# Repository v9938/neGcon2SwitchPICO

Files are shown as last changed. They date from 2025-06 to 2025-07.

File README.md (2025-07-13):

# 俺はneGconをアケアカのリッジレーサでつかいたいんじゃ、<BR>ついでにAirCombat22も対応しておいた for RP2040<BR>(neGcon2SwitchPICO)
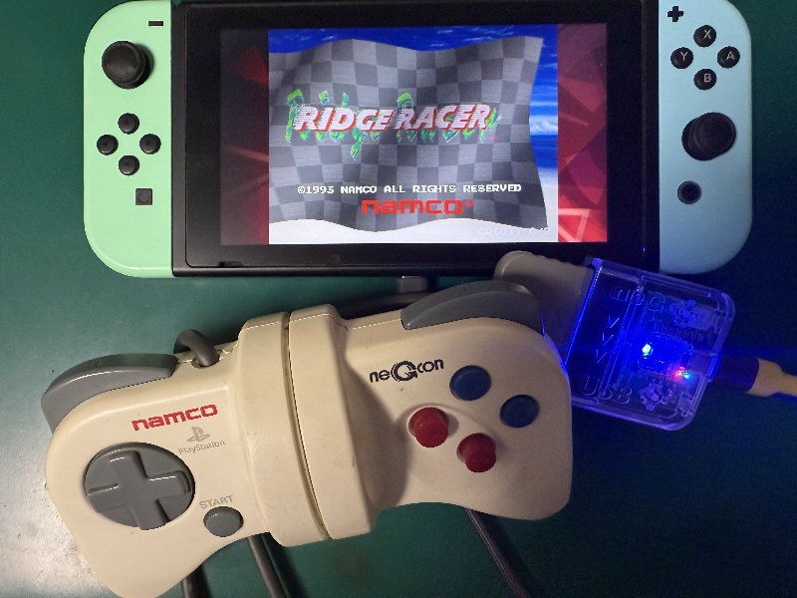
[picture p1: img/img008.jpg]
装置イメージ2
  

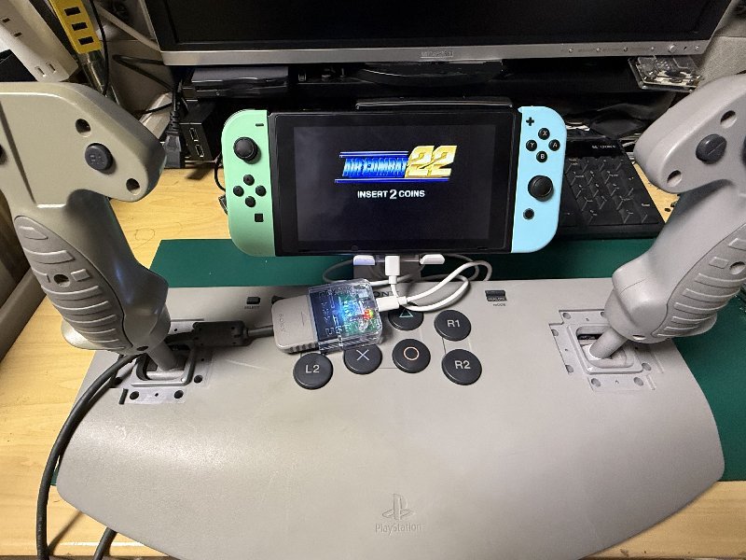
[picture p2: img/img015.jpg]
装置イメージ3
  

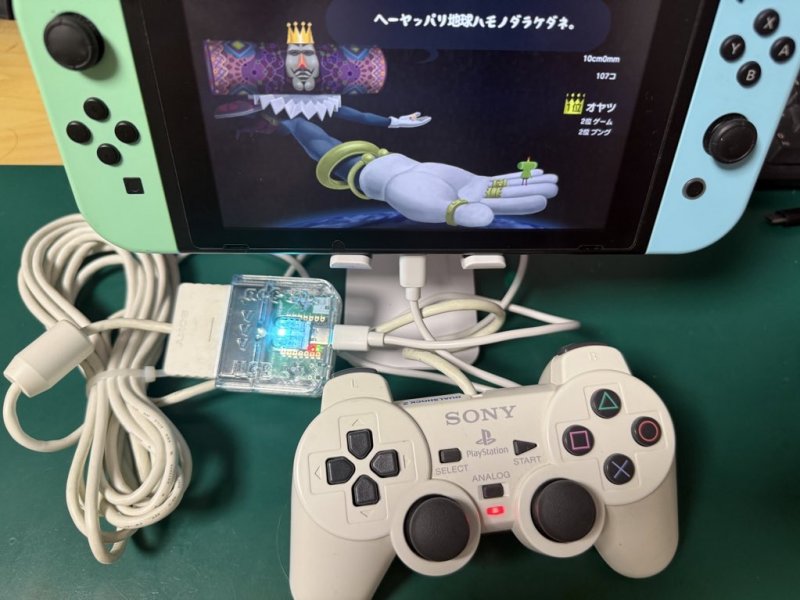
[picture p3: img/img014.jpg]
装置イメージ4
  

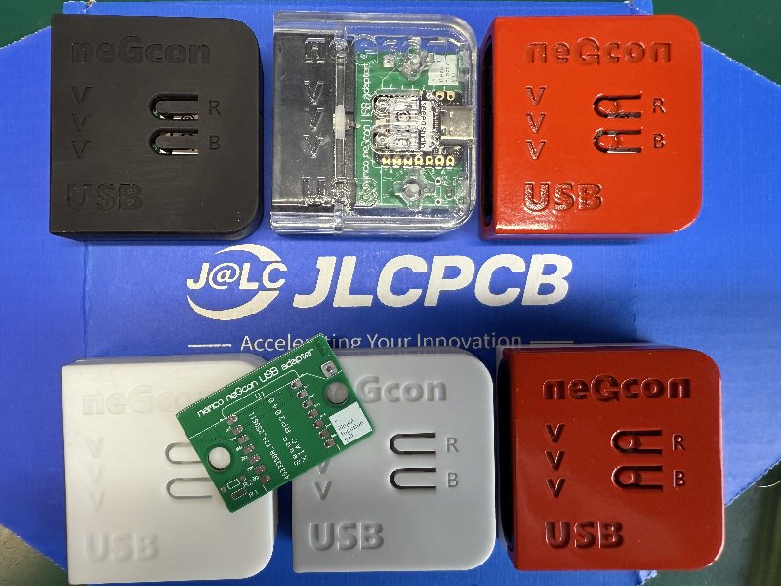
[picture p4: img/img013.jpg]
組み込みイメージ
  

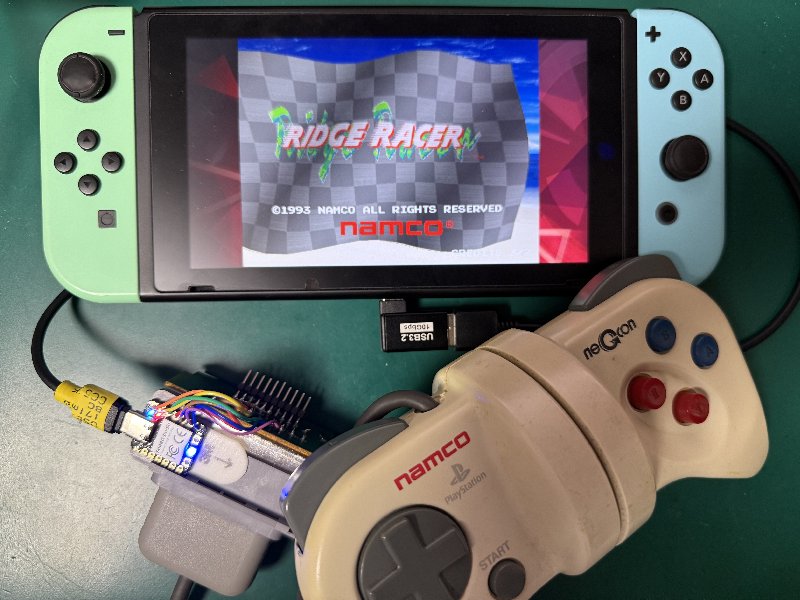
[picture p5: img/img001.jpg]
装置イメージ
  

良くあるプレステのコントローラをUSBゲームコントローラに変換するアダプタです。  
先日作ったNAMCO neGcon to Nintendo Switch ConverterはAVRで作っているため、  
色々と今だとイマイチなところが多いので改めてraspberry PICO系のマイコンボードで作り直しました。  

nintendo SWITCH向けに作りましたが、Windowsなどで汎用的に使用することが可能です。  

Nitendo Switch用アケアカ版リッジレーサでネジコンが使いたい！！

と勢いで雑に作った・・・のですが、頒布するために、もう少し真面目にコードを書き直して、  
バカでっかいFlightControllerをAirCombat22に対応させてみたり、  
DualShockの辺りをちゃんと、真面目に対応させて見たら悪くは無い出来の様な気がします。  

Switch2でも動きました・・・＼(^o^)／

## ■ 本製品の頒布について

下記ショップで取り扱っていただいています。  

###家電のKENちゃん  

完成品 (ケース色 赤/赤)  
<https://www.kadenken.com/view/item/000000001894>  

完成品 (ケース色 透明/赤)  
<https://www.kadenken.com/view/item/000000001895>  

キット版 (要半田付け　ケース無し）  
<https://www.kadenken.com/view/item/000000001893>  

※売り切れ時は、追加生産個数の参考にしたいので  
　「再入荷のお知らせを受け取る」おいていただけると幸いです。  

## 作り方
どこの誤家庭にもある、Seeed XIAO RP2040 または raspberry PICOボートとプレステのコントローラをつないでください。  
1KΩのプルアップ抵抗は必須です。DATAと3.3Vの間につけてください  

## PS1/PS2 joypad との配線 

|PSX Pin | PSX Signal | XIAO RP2040 | raspberry PICO | RP2040 Signal |
| :- |  :- |  :- |  :- |  :- |
| 1 | DAT | 9 | GP4 | MISO<BR>[need pullup by 1k owm registor to 3.3V] |
| 2 | CMD | 10 | GP3 | MOSI |
| 3 | 9V<BR> (for motor, If you not necessary NC)| (VCC) | (VSYS) | +5V |
| 4 | GND | GND | GND | Power GND |
| 5 | 3.3V | +3V3 | 3V3 | Power 3.3V |
| 6 | Attention | 7 | GP1 | GPIO1 (Controller Select) |
| 7 | CLK | 8 | GP2 | SCK |
| 8 | NC | - | - |
| 9 | ACK | - | - |

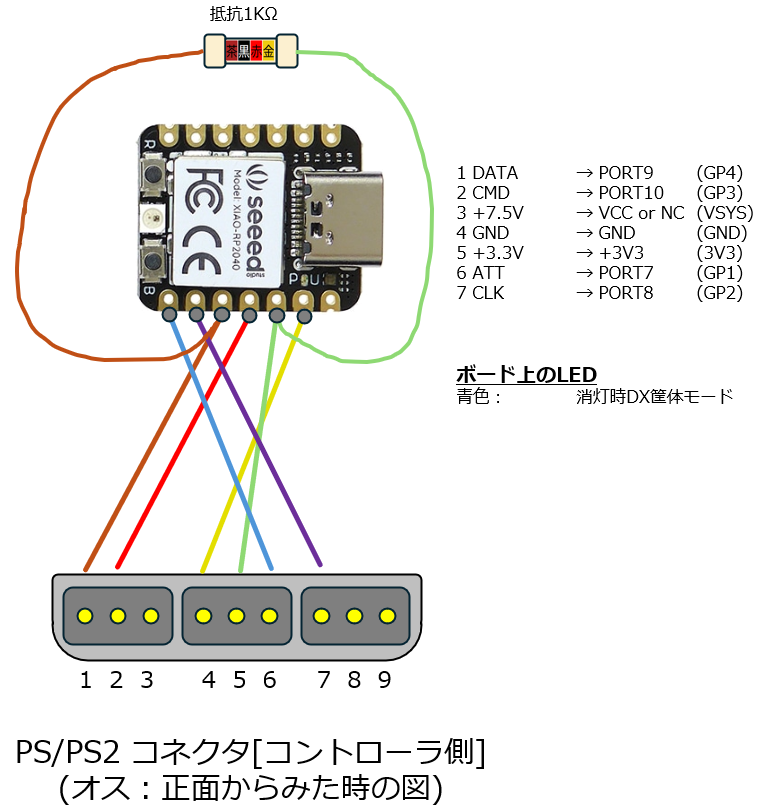
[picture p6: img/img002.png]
XIAO配線イメージ
  

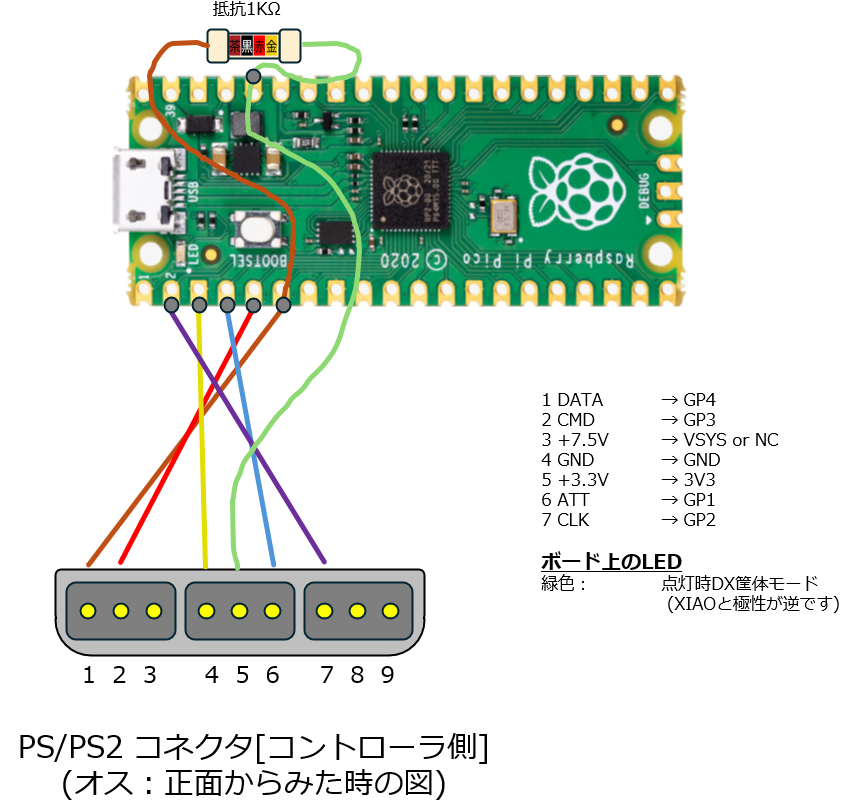
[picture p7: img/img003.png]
PICO装置イメージ
  

## Firmware書き込み方法
マイコンボード上にあるBボタンまたはBOOTSELボタンを押しながらUSBケーブルを接続してください。  
PCに接続した後も念のため数秒程度はボタンを離さないようにしてください。  
上手く接続できれば回路が「RPI-RP2」という名前で、USBメモリのように認識されます。  
「RPI-RP2」を開き、「xxxxx.uf2」ファイルをドラッグ&ドロップしたら完了です。  

「./firmware」のフォルダにコンパイル済のファイルが置いてあります。  

## ボタン配置について
接続するコントローラによってボタン配置や挙動が自動的に変更されます。  

## neGcon接続時のボタン配置
アケアカのリッジレーサに最適化されたモードです。  
neGcon接続時は[B]のBOOTボタンを押す事で設定を切り替えられます。(V1.20以降)  
また、neGcon/JoyCon/ANALOG JOYSTICK(SCPH-1110)接続時は、BOOTボタンをそのまま10秒程度更に長押しをすると、  
LEDが点滅し、最大角設定モードになります。(V1.30以降)  

アナログの感度に関しては、本Adapterでも補正を少しいれていますが、さらに調整が必要な場合は、  
アケアカ内のゲーム内の「設定」→「ボタン」→「こだわりのボタン設定」→「感度設定」で調整可能です。  

各モードのLED色は下記の通りです。  
| LEDの色 | モード |
| :- |  :- |
| 青色 | STD筐体モード  |
| 黄色 | DX筐体モード  |
| 紫色 | STD筐体モード(I/IIボタンSWAP)  |
| 緑色 | DX筐体モード(I/IIボタンSWAP)  |
| 白色 | デジタルモード  |
| 青点滅 | 最大角設定モード[ネジコン/ANALOG JOYSTICK(SCPH-1110)のみ]  |

### ボタン配置(アケアカ：リッジレーサ STD筐体モード)
|neGconボタン | Nintendo Switchコントローラ | 備考 |
| :- |  :- |  :- |
| ねじり (アナログ) | 左アナログスティックのX | 左アナログスティックのYは常にCenterです。 |
| I (アナログ) | 左アナログスティックのY 上方向 |  |
| II (アナログ) | 左アナログスティックのY 下方向 |  |
| L (アナログ) | Lボタン | 押し込まないと反応しません |
| R (デジタル) | Rボタン | |
| A (デジタル) | Aボタン | |
| B (デジタル) | Yボタン | |
| START (デジタル) | ＋ボタン |  |

### ボタン配置(アケアカ：リッジレーサ DX筐体モード)
| neGconボタン | Nintendo Switchコントローラ | 備考 |
| :- |  :- |  :- |
| ねじり (アナログ) | 左アナログスティックのX | 左アナログスティックのYは常にCenterです。 |
| I (アナログ) | ZRボタン | 押し込み量によって連射速度が変わります |
| II (アナログ) | ZLボタン | 押し込み量によって連射速度が変わります |
| L (アナログ) | Lボタン |  押し込まないと反応しません |
| R (デジタル) | Rボタン | |
| A (デジタル) | Aボタン | |
| B (デジタル) | Yボタン | |
| START (デジタル) | ＋ボタン |  |

## ANALOG JOYSTICK (SHPH-1110)接続時のボタン配置
アナログの感度に関しては、  
ゲーム内の「設定」→「ボタン」→「こだわりのボタン設定」→「感度設定」で調整可能です。  

### ボタン配置(アケアカ：AirCombat22モード)
| SHPH-1110 | Nintendo Switchコントローラ | 備考 |
| :- |  :- |  :- |
| 左スティック (アナログ) | 右アナログスティック | 操縦桿 |
| 右スティック (アナログ) | 左アナログスティック | スロットル |
| 右スティック HATスイッチ | 十字キー |  |
| SELECT | -ボタン |  |
| START  | +ボタン | メニュー |
| △ | Xボタン | クレジット |
| ○  | Aボタン | ミサイル |
| □ | Bボタン | バルカン |
| ✕  | Yボタン | START(視点切り替え)|
| L1  | ZLボタン |  |
| L2  | Lボタン |  |
| R1  | ZRボタン |  |
| R2  | Rボタン |  |

## DUALSHOCK/DUALSHOCK2接続時のボタン配置
### ボタン配置
| DUALSHOCK/DUALSHOCK2 | Nintendo Switchコントローラ | 備考 |
| :- |  :- |  :- |
| 左スティック (アナログ) | 左アナログスティック |  |
| 右スティック (アナログ) | 右アナログスティック |  |
| ○ (アナログ) | 未使用 | DUALSHOCK2のみ |
| □ (アナログ) | 未使用 | DUALSHOCK2のみ |
| 十字キー | 十字キー |  |
| SELECT | -ボタン |  |
| START  | +ボタン |  |
| △ | Xボタン | |
| ○  | Aボタン | |
| □ | Yボタン | |
| ✕  | Bボタン | |
| L1  | Lボタン |  |
| L2  | ZLボタン |  |
| R1  | Rボタン |  |
| R2  | ZRボタン |  |

## その他プレステコントローラ接続時のボタン配置
### ボタン配置
| プレステコントローラ | Nintendo Switchコントローラ | 備考 |
| :- |  :- |  :- |
| 十字キー | 十字キー |  |
| SELECT | -ボタン |  |
| START  | +ボタン |  |
| △ | Xボタン | |
| ○  | Aボタン | |
| □ | Yボタン | |
| ✕  | Bボタン | |
| L1  | Lボタン |  |
| L2  | ZLボタン |  |
| R1  | Rボタン |  |
| R2  | ZRボタン |  |

## 最大角度設定モードについて
neGcon/JoyCon/ANALOG JOYSTICK(SCPH-1110)接続時は、[B]のBOOTボタンを長押しをすると、  
LEDが点滅し、最大角設定モードになります。(V1.30以降)  

このモードで最大角を設定することでユーザ自身がneGcon/JoGconの捻り最大角度、  
ANALOG STICKでは操作時の最大角度を設定することができます。  

### 最大角の設定方法  
対応コントローラを接続し、[B]のBOOTボタンを10秒程度更に長押しすると当該モードに入ります。  

| LEDの色 | モード |
| :- |  :- |
| 青点滅 | 最大角設定モード[ネジコン/ANALOG JOYSTICK(SCPH-1110)のみ]  |

当該モードに入ったら、設定したい最大角度を実際に操作し、パッドの「スタートボタン」を一回押してください。  
LEDの点滅が止まり、元のモードに戻ります。設定値は自動で保存されます。  

初期値に戻したい場合は、コントローラやのニュートラル状態にして、パッドの「スタートボタン」を押してください。  
また、キャンセルは、[B]のBOOTボタンを1回押してください。  

## 専用基板および筐体について

下記フォルダーに、PCBデータと筐体データがおいてあるので JLCPCBさんの辺りに、  
まとめてぶん投げると一番安い仕様を選択すれば大体、基板は$5+送料、筐体は$8+送料で仕上がるはずです。  

<https://github.com/v9938/neGcon2SwitchPICO/tree/main/pcb>

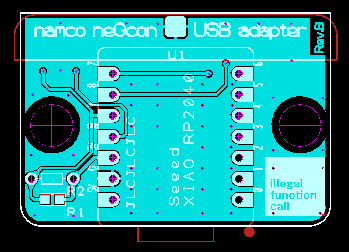
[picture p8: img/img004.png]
基板イメージ
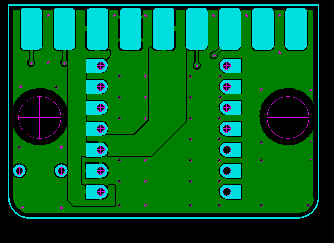
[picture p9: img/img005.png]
基板イメージ2
   
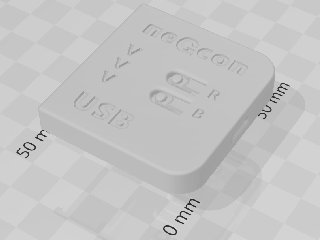
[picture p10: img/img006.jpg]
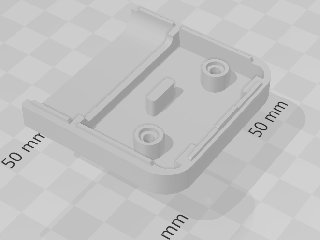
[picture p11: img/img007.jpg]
   

※専用基板および完成品の頒布は現在準備中です。  
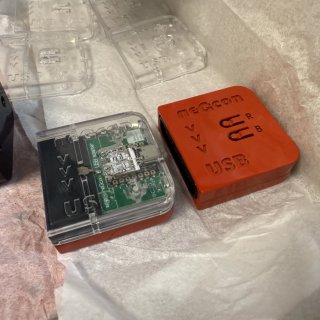
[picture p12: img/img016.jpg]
頒布筐体
  

## パーツリスト  
|部品番号 | 部品名 | 参考 購入先 |
| :- |  :- |  :- |
| U1 | Seeed XIAO RP2040 | 秋月電子 ￥980 |
| R1 | 未実装 | ※R1かR2のどちらかを実装 |
| R2 | 1KΩ1/6W | 秋月電子 1袋100本入 ￥120 |
| 番号なし | PSコントローラコネクタ | 秋月電子 Vstone VS-C1接続用基板側コネクター ￥300 |
| その他 | 2.6mmx12mm タッピングねじ(サラ) | 筐体で使う固定のネジになります。 |

## 組み立て方法  
それほどパーツ数が多くないので、下記写真の様に組み立てください。  
PSコネクタは実装後に、曲げると壊れるので表側のタブも少し曲げて、基板にハンダした方が良いです。  

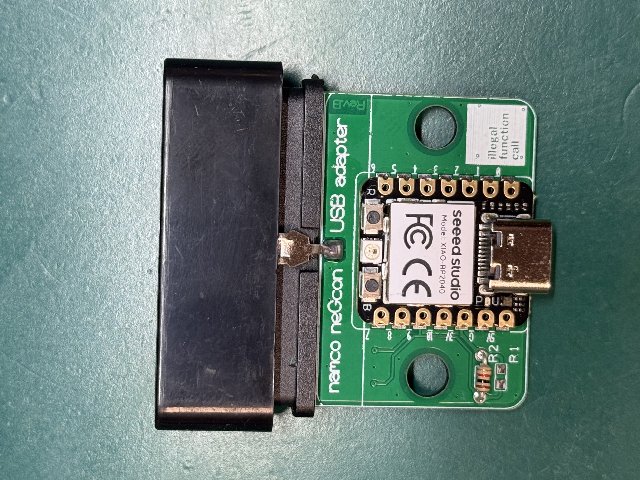
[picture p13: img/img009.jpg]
基板表
  
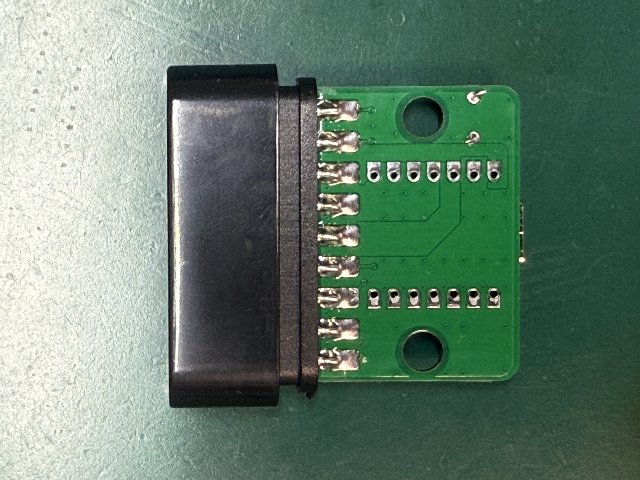
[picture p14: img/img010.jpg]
基板裏
  

筐体に入れる場合はマイコンボードに付属のヘッダピンは使わない様にして実装してください  
また、PSコネクタを半田付けする時に筐体に一度組み込んでハンダしましょう。  
(1mm程度基板から浮いて実装します)  

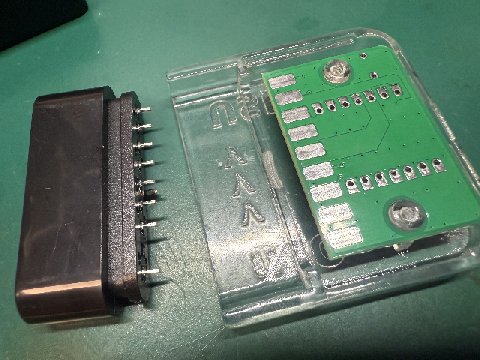
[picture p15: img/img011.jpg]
組み込み1
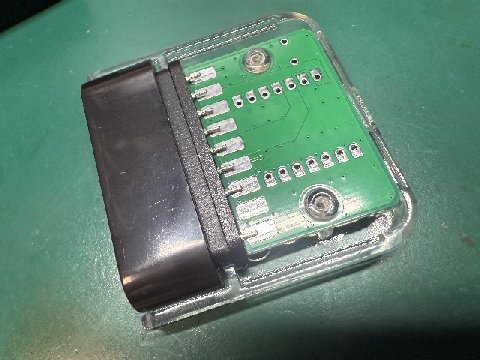
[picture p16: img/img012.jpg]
組み込み2
  

## コントローラの遅延について  
本変換機の遅延は、USB Data Frameで1パケット分になります。  
変換機でのUSB Data Frameの要求値は1msですが、USB Data Frameの送信間隔はHOSTが決めています。  
そのため、実際のキー入力から遅延時間はHOSTにより変わります。  
こちらで計測した範囲では以下の様になっていました。  

|USB HOST | USB Data Frame間隔 | 遅延時間 |
| :- |  :- |  :- |
| Switch/Switch2 | 約7.5ms | 15ms～22.5ms |
| Windows系 | 約1.5ms | 3ms～4.5ms |

### PS1 CONTROLLER(SCPH-1080)のLボタンを押した時の実測値  
※Lボタンを押した時が0ms →「USB DATA 10 00 08 80 80 80 80 00」 がLボタンを押した時のデータ  

■nintendo SWITCH2
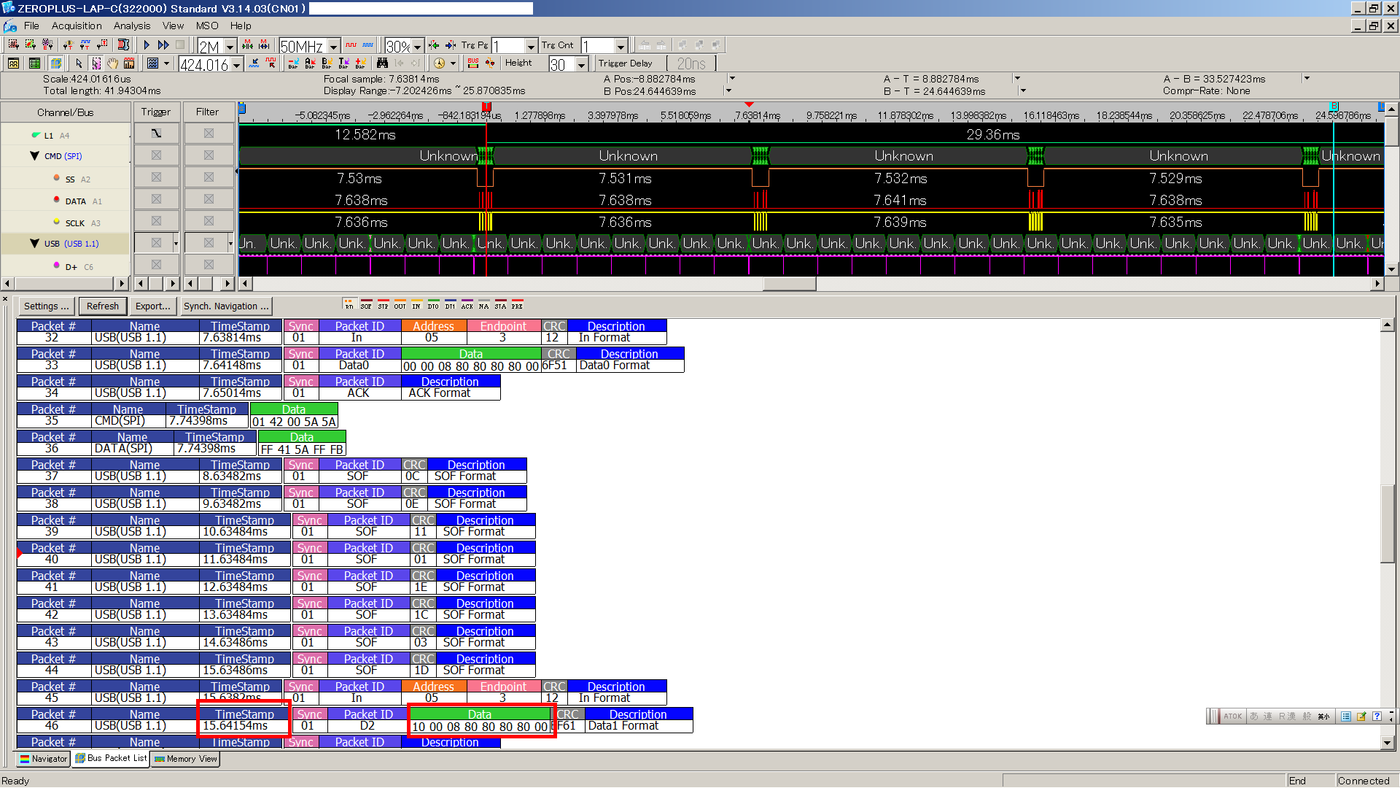
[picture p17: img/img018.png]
遅延Switch2
 
■Microsoft Windows11
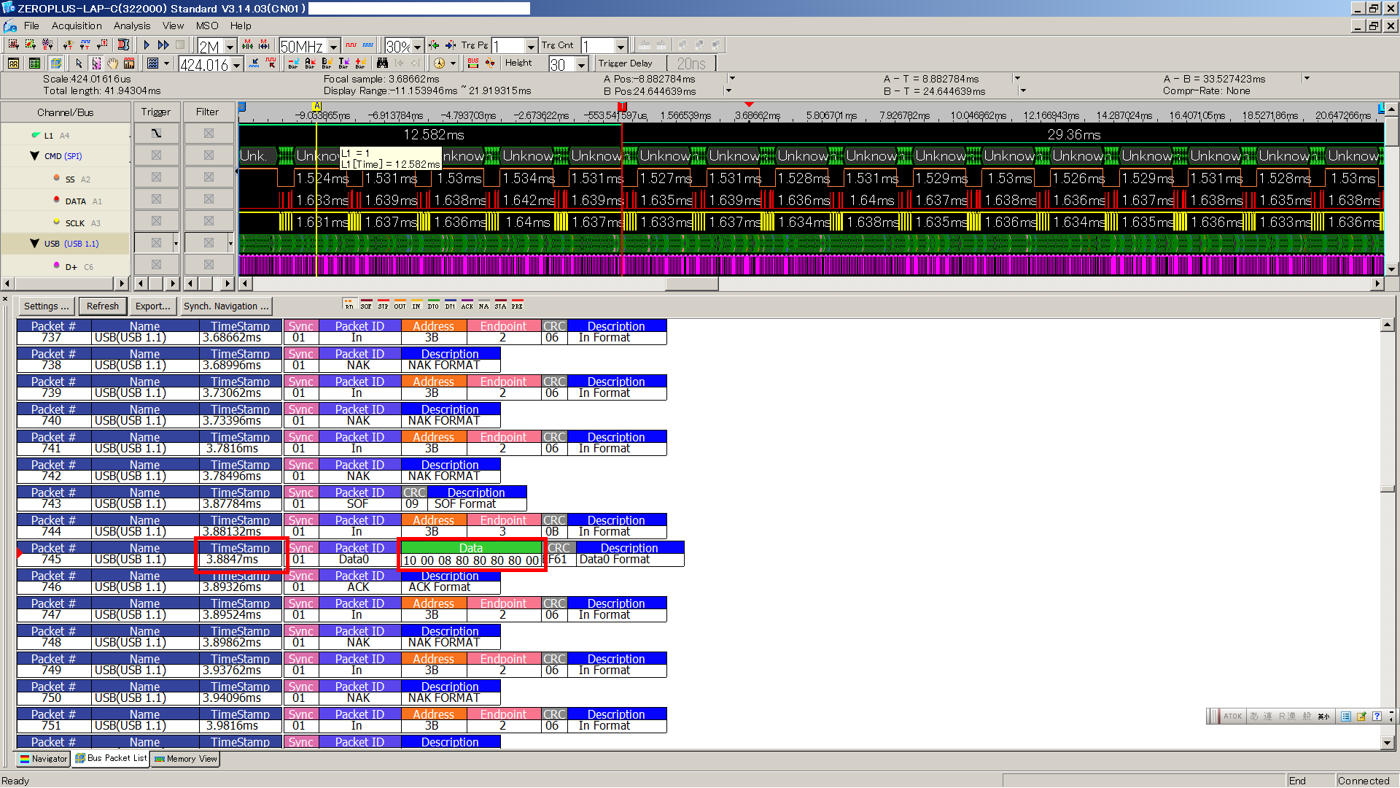
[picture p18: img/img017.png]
遅延Windows
 

## 使用したlibraryについて  
本ソフトは下記libraryを利用しています。  

### Adafruit_NeoPixel
<https://github.com/adafruit/Adafruit_NeoPixel>  

### Adafruit_TinyUSB_Library
<https://github.com/adafruit/Adafruit_TinyUSB_Arduino>

### PsxNewLib  
<https://github.com/SukkoPera/PsxNewLib>  

### SwitchControllerPico  
<https://github.com/sorasen2020/SwitchControllerPico>  

## おまけ  
JLCPCBさんがやっているOpen-Source Engineer Storiesに参加中です。  
下記ポストをリポストしてもらえると嬉しいです。  

<https://x.com/v9938/status/1938441988971405770>

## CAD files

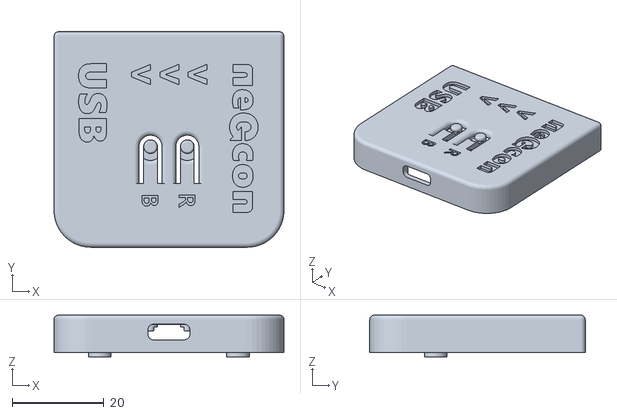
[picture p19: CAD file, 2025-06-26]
pcb/case/NEG2USB_CASE_TOP.stl
50.0 x 46.9 x 9.10

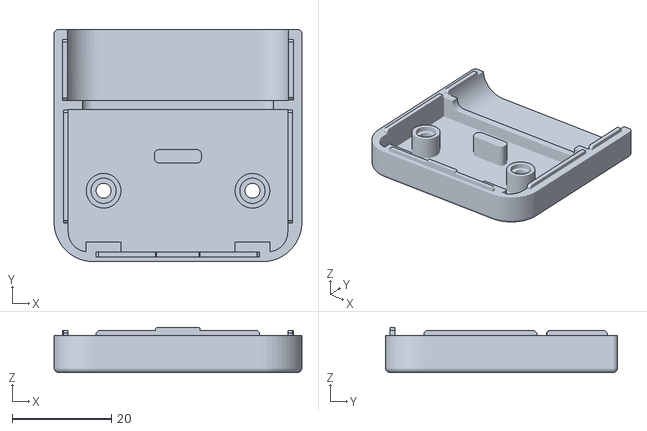
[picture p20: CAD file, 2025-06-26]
pcb/case/NEG2USB_CASE_BOTTOM.stl
50.0 x 46.9 x 9.10

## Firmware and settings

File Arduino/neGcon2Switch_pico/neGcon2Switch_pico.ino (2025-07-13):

////////////////////////////////////////////////////////////////////////
//
// PSX NeG Controller to Switch Joystick Sample
// raspberry PICO version
// Copyright 2025 @V9938
//
//	25/06/07 V0.1	1st version
//	25/06/07 V0.2	fix I/II/L Analog Value
//  25/06/10 V0.5   1st PICO version
//  25/06/11 V0.6   Support NeoPixel
//  25/06/11 V0.7   Support DX mode
//  25/07/03 V1.0   Support Aircombat22 mode with SCPH1110
//                  Fixed bug Digtal mode setting
//  25/07/03 V1.1   Support Controller HORI ANALOG SHINDOU PAD
//  25/07/12 V1.2   Support I/II button swap mode
//                  Fixed bug neGcon mode setting
//                  Support save & restore neGcon mode
//                  Change LED Pattern standard PSX Controller
//                  Adjust I/II button value (x1.1)
//  25/07/13 V1.3   Support maximum tilt setting(neGcon/Analog Stick).
//
//
// This program requires same librarys
// "Adafruit_NeoPixel"
//
// "PsxNewLib”
// https://github.com/SukkoPera/PsxNewLib
//
// "SwitchControllerPico"
// https://github.com/sorasen2020/SwitchControllerPico
//
// USB Stack setting "Adafruit_TinyUSB_Library"
// If modifying the PID/VID values in 'board.txt' is not possible at v2.xx IDE,
// please add the settings to the file listed below."
//
// C:\Users\[UserName]\Documents\Arduino\libraries\Adafruit_TinyUSB_Library\src\arduino\Adafruit_USBD_Device.cpp
// // added custom PID
// #define USB_PRODUCT     "Pokken Tournament DX Pro Pad"
// #define USB_MANUFACTURER "HORI"
// #define USB_VID 0x0f0d
// #define USB_PID 0x0092
//
////////////////////////////////////////////////////////////////////////

#include "Arduino.h"
#include "PsxControllerPICO_HwSpi2.h"
#include "SwitchControllerPico.h"
#include "NintendoSwitchControllPico.h"
#include <Adafruit_NeoPixel.h>
#include <EEPROM.h>

//#define SERIALVAL_OUT

// EEPROMの設定
#define EEPROMSIZE 256
// EEPROMのアドレス配置
#define EEPADR_NEGMODE 3
#define EEPADR_NEG_NEGMAX 4
#define EEPADR_ANALOG_STICKMAX 5

// neGcon ハンドルアナログ値の補正
// これ以上の補正が必要な場合は、設定→ボタン→こだわりのボタン設定→感度設定を弄ってください。
#define NEG_CALIB 1.2

// neGcon ボタン アナログ値の補正
// これ以上の補正が必要な場合は、設定→ボタン→こだわりのボタン設定→感度設定を弄ってください。
#define NEG_CALIB_B 1.1

//NeoPixelの設定
#define NUMPIXELS 1
#define NEO_PWR 11  //GPIO11
#define NEOPIX 12   //GPIO12

//Stick Mode
#define MODE_STD 0
#define MODE_DX 1
#define MODE_AIRCON22 2
#define MODE_ANALOG 3
#define MODE_STDSWAP 4
#define MODE_DXSWAP 5
#define MODE_NEGDIGTAL 6
#define MODE_DIGTAL 7

#define MODE_SETTING_NEG 98
#define MODE_LOST 99

//PWM modeの1LOOP回数 数字を細かくするとON-OFF間隔が短くなる(8ms x PWM_LOOP)
#define PWM_LOOP 30


/** \brief Pin used for Controller Attention (ATTN)
 *
 * This pin makes the controller pay attention to what we're saying. The shield
 * has pin 10 wired for this purpose.
 */
const unsigned int PIN_PS2_CMD = 4;  //MOSI
const unsigned int PIN_PS2_DAT = 3;  //MOSO
const unsigned int PIN_PS2_CLK = 2;  //SCK
const unsigned int PIN_PS2_ATT = 1;  //CS

// Set up the speed, data order and data mode
static SPISettings spiSettings(250000, LSBFIRST, SPI_MODE3);

/** \brief Pin for Button Press Led
 *
 * This led will light up whenever a button is pressed on the controller.
 */
const unsigned int PIN_CONNECT = 25;   // BLUE
const unsigned int PIN_ERRORLED = 17;  // RED
const unsigned int PIN_GOODLED = 16;   // GREEN

bool haveController = false;
/** \brief Dead zone for analog sticks
 *  
 * If the analog stick moves less than this value from the center position, it
 * is considered still.
 * 
 * \sa ANALOG_IDLE_VALUE
 */
const byte ANALOG_DEAD_ZONE = 50U;

PsxControllerPICO_HwSpi<PIN_PS2_ATT> psx;

const uint8_t desc_hid_report[] = {
  CUSTOM_DESCRIPTOR
};

Adafruit_USBD_HID usb_hid(desc_hid_report, sizeof(desc_hid_report), HID_ITF_PROTOCOL_NONE, 2, false);
Adafruit_NeoPixel pixels(NUMPIXELS, NEOPIX, NEO_GRB + NEO_KHZ800);

// Controller Type
const char ctrlTypeUnknown[] PROGMEM = "Unknown";
const char ctrlTypeDualShock[] PROGMEM = "Dual Shock";
const char ctrlTypeDsWireless[] PROGMEM = "Dual Shock Wireless";
const char ctrlTypeGuitHero[] PROGMEM = "3rd Party Controller";
const char ctrlTypeOutOfBounds[] PROGMEM = "(Out of bounds)";

const char* const controllerTypeStrings[PSCTRL_MAX + 1] PROGMEM = {
  ctrlTypeUnknown,
  ctrlTypeDualShock,
  ctrlTypeDsWireless,
  ctrlTypeGuitHero,
  ctrlTypeOutOfBounds
};


// Controller Protocol
const char ctrlProtoUnknown[] PROGMEM = "Unknown";
const char ctrlProtoDigital[] PROGMEM = "Digital";
const char ctrlProtoDualShock[] PROGMEM = "Dual Shock";
const char ctrlProtoDualShock2[] PROGMEM = "Dual Shock 2";
const char ctrlProtoFlightstick[] PROGMEM = "Flightstick（SCPH-1110)";
const char ctrlProtoNegcon[] PROGMEM = "namco neGcon";
const char ctrlProtoJogcon[] PROGMEM = "namco Jogcon";
const char ctrlProtoOutOfBounds[] PROGMEM = "(Out of bounds)";

const char* const controllerProtoStrings[PSPROTO_MAX + 1] PROGMEM = {
  ctrlProtoUnknown,
  ctrlProtoDigital,
  ctrlProtoDualShock,
  ctrlProtoDualShock2,
  ctrlProtoFlightstick,
  ctrlProtoNegcon,
  ctrlProtoJogcon,
  ctrlTypeOutOfBounds
};

const Hat hatValue[0x10] = {
  Hat::CENTER,
  Hat::UP,
  Hat::RIGHT,
  Hat::UP_RIGHT,
  Hat::DOWN,
  Hat::CENTER,
  Hat::RIGHT_DOWN,
  Hat::CENTER,
  Hat::LEFT,
  Hat::LEFT_UP,
  Hat::CENTER,
  Hat::CENTER,
  Hat::DOWN_LEFT,
  Hat::CENTER,
  Hat::CENTER,
  Hat::CENTER
};

USB_JoystickReport_Input_t t_joystickInputData;
byte ledLx, ledLy, ledRx, ledRy, ledB1, ledB2, ledBL;
byte stickMode;
byte lxMax;
byte analogLxMax;


// EEPROMのClear関数
void eepromFormat() {
  Serial.println(F("EEP Write!"));
  for (int i = 0; i < EEPROMSIZE; i++) {
    EEPROM.write(i, 0);
  }
  EEPROM.write(0, 'c');
  EEPROM.write(1, 'n');
  EEPROM.write(2, 'f');
  EEPROM.write(EEPADR_NEGMODE, MODE_STD);
  EEPROM.write(EEPADR_NEG_NEGMAX, 255 / ((NEG_CALIB - 1) / 2 + 1));
  EEPROM.write(EEPADR_ANALOG_STICKMAX, 255);
  EEPROM.commit();
}

// EEPROM領域の確認
bool eepromCheck() {
  if (EEPROM.read(0) != 'c') return false;
  if (EEPROM.read(1) != 'n') return false;
  if (EEPROM.read(2) != 'f') return false;
  return true;
}

// neGconモードひねり値の最大値の復帰
byte restoreNegDegMax() {
  byte tmp;
  tmp = EEPROM.read(EEPADR_NEG_NEGMAX);

  // 有効値Check
  if (tmp < 0x80) {
    tmp = 255 / ((NEG_CALIB - 1) / 2 + 1);
    Serial.println(F("EEP Write!"));
    EEPROM.write(EEPADR_NEG_NEGMAX, tmp);
    EEPROM.commit();
  }

  return tmp;
}

// アナログスティックモードひねり値の最大値の復帰
byte restoreAnaDegMax() {
  byte tmp;
  tmp = EEPROM.read(EEPADR_ANALOG_STICKMAX);

  // 有効値Check
  if (tmp < 0x80) {
    tmp = 255;

    Serial.println(F("EEP Write!"));
    EEPROM.write(EEPADR_ANALOG_STICKMAX, tmp);
    EEPROM.commit();
  }

  return tmp;
}

// neGconモード設定の復帰
byte restoreNegStickMode() {
  byte tmp;
  tmp = EEPROM.read(EEPADR_NEGMODE);

  // 有効値Check
  switch (tmp) {
    case MODE_STD:
    case MODE_STDSWAP:
    case MODE_DX:
    case MODE_DXSWAP:
      break;

    default:
      tmp = MODE_STD;
      Serial.println(F("EEP Write!"));
      EEPROM.write(EEPADR_NEGMODE, tmp);
      EEPROM.commit();
      break;
  }

  return tmp;
}

// 絶対値 計算関数
int absoluteXY(byte lx) {
  int lx_tmp;

  if (lx < 0x80) lx_tmp = (int)(0xFF - lx);
  else lx_tmp = (int)lx;
  return lx_tmp;
}

// 補正値計算
int adjustXY(byte lx, byte max) {
  int lx_tmp;

  if (lx > 0x80) {
    lx_tmp = (int)((lx - 0x80)) * 0x7f / (max - 0x80);
    if (lx_tmp > 0x7f) lx_tmp = 0x7f;
    lx_tmp = 0x80 + lx_tmp;
  } else {
    lx_tmp = (int)((0x80 - lx)) * 0x7f / (max - 0x80);
    if (lx_tmp > 0x80) lx_tmp = 0x80;
    lx_tmp = 0x80 - lx_tmp;
  }
  return lx_tmp;
}


// CPU1では、NeoPixel LEDの点灯処理をさせる
void setup1() {  //core 0
  pixels.begin();
  pinMode(NEO_PWR, OUTPUT);
  digitalWrite(NEO_PWR, HIGH);
  delay(1000);
}
void loop1() {  //core 0
  static byte heartbeat_num = 0;
  static bool heartbeat_flag = true;

  switch (stickMode) {
      // neGconモード時の点灯パターン
    case MODE_STD:
      pixels.setPixelColor(0, pixels.Color(ledB1 / 2 + ledBL / 2, ledB2 / 2 + ledBL / 2, ledLx));
      pixels.show();
      break;

      // neGconモード時の点灯パターン（I/II SWAPモード)
    case MODE_STDSWAP:
      pixels.setPixelColor(0, pixels.Color(0x80 - ledB1 + ledB2, 0, ledLx));
      pixels.show();
      break;

      // neGconモード時の点灯パターン DXモード時のパターン
    case MODE_DX:
      pixels.setPixelColor(0, pixels.Color(ledB2 / 2 + ledBL / 2, ledLx, ledB1 / 2 + ledBL / 2));
      pixels.show();
      break;

      // neGconモード時の点灯パターン DXモード時のパターン（I/II SWAPモード)
    case MODE_DXSWAP:
      pixels.setPixelColor(0, pixels.Color(0, 0x80 - ledB1 + ledB2, ledLx / 2 + ledBL / 2));
      pixels.show();
      break;

    // neGconモード時の点灯パターン デジタルモード時
    case MODE_NEGDIGTAL:
      pixels.setPixelColor(0, pixels.Color(0x20, 0x20, 0x20));
      pixels.show();
      break;

      // フライトコントローラ接続時の点灯パターン
    case MODE_AIRCON22:
      pixels.setPixelColor(0, pixels.Color(ledRy / 4, ledLx / 8, ledRy / 8 + 0x40));
      pixels.show();
      break;

      // DualShock接続時の点灯パターン
    case MODE_ANALOG:
      pixels.setPixelColor(0, pixels.Color(0, ledRy / 4 + ledLx / 2, ledRy / 2 + ledRx / 4));
      pixels.show();
      break;

      // その他接続時の点灯パターン
    case MODE_DIGTAL:
      pixels.setPixelColor(0, pixels.Color(0x0, 0x4, 0x8));
      pixels.show();
      break;

    case MODE_SETTING_NEG:
      pixels.setPixelColor(0, pixels.Color(0x0, 0x0, heartbeat_num));
      pixels.show();
      break;


      // 残念賞
    default:
      pixels.clear();
      pixels.show();
      break;
  }

  //LEDの点滅処理数値計算
  if (heartbeat_num == 0) heartbeat_flag = true;
  else if (heartbeat_num == 255) heartbeat_flag = false;

  if (heartbeat_flag) heartbeat_num++;
  else heartbeat_num--;
}

void setup() {
  switchcontrollerpico_init();
  // wait until device mounted
  while (!TinyUSBDevice.mounted()) delay(1);
  switchcontrollerpico_reset();
  pinMode(PIN_CONNECT, OUTPUT);
  pinMode(PIN_ERRORLED, OUTPUT);
  pinMode(PIN_GOODLED, OUTPUT);

  digitalWrite(PIN_CONNECT, HIGH);
  digitalWrite(PIN_ERRORLED, HIGH);
  digitalWrite(PIN_GOODLED, HIGH);


  gpio_init(PIN_PS2_CLK);  //SCK
  gpio_set_dir(PIN_PS2_CLK, GPIO_OUT);
  gpio_put(PIN_PS2_CLK, HIGH);

  gpio_init(PIN_PS2_CMD);  //MOSI
  gpio_set_dir(PIN_PS2_CMD, GPIO_OUT);
  gpio_put(PIN_PS2_CMD, HIGH);

  gpio_init(PIN_PS2_DAT);  //MISO
  gpio_set_dir(PIN_PS2_DAT, GPIO_IN);
  gpio_pull_up(PIN_PS2_DAT);

  gpio_init(PIN_PS2_ATT);  //SS(GPIO)
  gpio_set_dir(PIN_PS2_ATT, GPIO_OUT);
  gpio_put(PIN_PS2_ATT, HIGH);

  SPI.beginTransaction(spiSettings);
  EEPROM.begin(EEPROMSIZE);
  if (eepromCheck() != true) eepromFormat();

  //	SPI.setSCK(PIN_PS2_CLK);
  //	SPI.setMOSI(PIN_PS2_CMD);
  //	SPI.setMISO(PIN_PS2_DAT);

  lxMax = restoreNegDegMax();
  analogLxMax = restoreAnaDegMax();
  stickMode = MODE_LOST;
  delay(300);

  //	Serial.begin (115200);
  //	while (!Serial) {
  // Wait for serial port to connect on Leonardo boards
  //  		digitalWrite (PIN_BUTTONPRESS, (millis () / 333) % 2);
  //  }
  Serial.println(F("Ready!"));
}

void loop() {
  static int loop_num = 0;
  static int sBootSel = 0;
  static byte beforeStickMode;
  static bool changeNegStickMode;
  static byte slx, sly, sb1, sb2, sbL;
  static byte srx, sry;

  byte l_x, l_y, l_b1, l_b2, l_bL;
  byte lx_org, ly_org, b1_org, b2_org, bL_org;
  byte rx_org, ry_org;
  byte r_x, r_y;
  int l_x_tmp, xy_tmp;


  static PsxControllerType psxContType;
  PsxControllerProtocol psxStickMode;
  static PsxControllerProtocol OldpsxStickMode;

  bool bSendData;

  // BOOTスイッチの処理
  // 現状MODE選択に割り当てている
  if (BOOTSEL) {
    digitalWrite(PIN_ERRORLED, LOW);
    if (sBootSel < 3000) {
      if (sBootSel == 0) changeNegStickMode = false;
      if (sBootSel == 9) {
        changeNegStickMode = true;
        Serial.print(F("Current Stick mode is: "));
        Serial.println(stickMode);
      }
      if (sBootSel == 2999) {
        if ((OldpsxStickMode == PSPROTO_NEGCON) || (OldpsxStickMode == PSPROTO_JOGCON) || (OldpsxStickMode == PSPROTO_FLIGHTSTICK)) {
          Serial.println(F("Set Config mode"));
          changeNegStickMode = false;
          beforeStickMode = stickMode;
          stickMode = MODE_SETTING_NEG;
        }
      }
      sBootSel++;
    }
  } else {
    digitalWrite(PIN_ERRORLED, HIGH);
    if (changeNegStickMode) {

      // ネジコンモード時のモード選択処理
      if ((OldpsxStickMode == PSPROTO_NEGCON) || (OldpsxStickMode == PSPROTO_JOGCON)) {
        if (stickMode == MODE_STD) stickMode = MODE_DX;
        else if (stickMode == MODE_DX) stickMode = MODE_STDSWAP;
        else if (stickMode == MODE_STDSWAP) stickMode = MODE_DXSWAP;
        else if (stickMode == MODE_DXSWAP) stickMode = MODE_NEGDIGTAL;
        else if (stickMode == MODE_NEGDIGTAL) stickMode = MODE_STD;
        else stickMode == MODE_STD;

        Serial.println(F("EEP Write!"));
        EEPROM.write(EEPADR_NEGMODE, stickMode);
        EEPROM.commit();
      }

      // 設定のキャンセル処理
      if (stickMode == MODE_SETTING_NEG) stickMode = beforeStickMode;

      Serial.print(F("Change Stick mode is: "));
      Serial.println(stickMode);
    }

    changeNegStickMode = false;
    sBootSel = 0;
  }


  if (!haveController) {
    if (psx.begin()) {
      //    	digitalWrite(PIN_CONNECT, LOW);
      Serial.println(F("Controller found!"));
      delay(300);
      if (!psx.enterConfigMode()) {
        //古いタイプのコントローラではHOSTから設定できないのでこちらに来る
        Serial.println(F("Cannot enter config mode"));
        psxContType = psx.getControllerType();
        Serial.print(F("Controller Type is: "));
        Serial.println(controllerTypeStrings[psxContType < PSCTRL_MAX ? static_cast<byte>(psxContType) : PSCTRL_MAX]);
        psx.read();  // Make sure the protocol is up to date
                     //     digitalWrite(PIN_ERRORLED, LOW);

      } else {
        //Dual shock以降はこちらに来る。HORIのアナログ振動ジョイパッドはDUALSHOCKに設定される
        psxContType = psx.getControllerType();
        Serial.print(F("Controller Type is: "));
        Serial.println(controllerTypeStrings[psxContType < PSCTRL_MAX ? static_cast<byte>(psxContType) : PSCTRL_MAX]);

        if (!psx.enableAnalogSticks()) {
          Serial.println(F("Cannot enable analog sticks"));
        }

        if (!psx.enableAnalogButtons()) {
          Serial.println(F("Cannot enable analog buttons"));
        }

        if (!psx.exitConfigMode()) {
          Serial.println(F("Cannot exit config mode"));
        }
      }

      psx.read();  // Make sure the protocol is up to date
                   //     	digitalWrite(PIN_ERRORLED, LOW);

      psxStickMode = psx.getProtocol();
      Serial.print(F("Controller Protocol is: "));
      Serial.println(controllerProtoStrings[psxStickMode < PSPROTO_MAX ? static_cast<byte>(psxStickMode) : PSPROTO_MAX]);
      haveController = true;
    }
  } else {
    if (!psx.read()) {
      //     	digitalWrite(PIN_CONNECT, HIGH);
      digitalWrite(PIN_GOODLED, HIGH);

      Serial.println(F("Controller lost :("));
      haveController = false;
      psxContType = PSCTRL_UNKNOWN;  //Stickモードを更新しておく
      psxStickMode = PSPROTO_UNKNOWN;
      OldpsxStickMode = PSPROTO_UNKNOWN;
      stickMode = MODE_LOST;

    } else {
      digitalWrite(PIN_GOODLED, LOW);  //Controller認識OK
      // PWM mode用LOOP回数処理
      if (loop_num >= PWM_LOOP) loop_num = 0;
      else loop_num++;
      psxStickMode = psx.getProtocol();  //現在のStickモードを取得

      if (psxStickMode != OldpsxStickMode) {
        // 動的にコントローラモードの変更されるもののみ列挙
        // neGconは、モード切替が無いのでここでは列挙しない
        if (psxStickMode == PSPROTO_DIGITAL) stickMode = MODE_DIGTAL;
        if (psxStickMode == PSPROTO_FLIGHTSTICK) stickMode = MODE_AIRCON22;
        if ((psxStickMode == PSPROTO_DUALSHOCK) || (psxStickMode == PSPROTO_DUALSHOCK2)) stickMode = MODE_ANALOG;
        if ((psxStickMode == PSPROTO_NEGCON) || (psxStickMode == PSPROTO_JOGCON)) stickMode = restoreNegStickMode();

        Serial.print(F("Controller Protocol is: "));
        Serial.println(controllerProtoStrings[psxStickMode < PSPROTO_MAX ? static_cast<byte>(psxStickMode) : PSPROTO_MAX]);
      }
      OldpsxStickMode = psxStickMode;

      // buttonデータを一端初期化
      t_joystickInputData.Button = 0;


      // 以下各スティック向け処理を以下に記述
      switch (psxStickMode) {

        // SPCH-1110 FLIGHTSTICK mode (AirCombat22 mode)
        // ボタン設定はdefaultのモノに最適化してあります
        case PSPROTO_FLIGHTSTICK:
          //右スティックの処理
          if (psx.getRightAnalog(lx_org, ly_org)) {
            l_x = lx_org;
            l_y = ly_org;
          } else {
            l_x = 0x80;
            l_y = 0x80;
          }

          //左スティックの処理
          if (psx.getLeftAnalog(rx_org, ry_org)) {
            r_x = rx_org;
            r_y = ry_org;
          } else {
            r_x = 0x80;
            r_y = 0x80;
          }
          if (l_x != slx || l_y != sly || r_x != srx || r_y != sry) {
            slx = l_x;
            sly = l_y;
            srx = r_x;
            sry = r_y;

#ifdef SERIALVAL_OUT
            Serial.print(F("DEBUG : (ORG)LX: "));
            Serial.print(l_x);
            Serial.print(F(" LY: "));
            Serial.print(l_y);
            Serial.print(F(" RX: "));
            Serial.print(r_x);
            Serial.print(F(" RY: "));
            Serial.print(r_y);
#endif
            l_x = (byte)adjustXY(l_x, analogLxMax);
            l_y = (byte)adjustXY(l_y, analogLxMax);
            r_x = (byte)adjustXY(r_x, analogLxMax);
            r_y = (byte)adjustXY(r_y, analogLxMax);
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

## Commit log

2025-06-10 V0.7 1st public release
    PICO版の初版releaseです。
2025-06-26 Add PCB/3DP Data
    基板と３Dプリント向けの筐体データを追加しました。
    [NEG2USB - Bottom Copper (Resist).gbr, NEG2USB - Bottom Copper.gbr, NEG2USB - Drill Ident Drawing - [Through Hole].gbr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]
2025-07-03 Support Aircombat22 mode with SCPH1110 & Fixed bug Digtal mode setting
    頒布版初期FW
    ・SCPH-1110接続時にエアーコンバット22に特化した配置モードを追加しました
    ・デジタルモード時の挙動が誤っていたバグを修正しました。
    ・DUALSHOCK/DUALSHOCK2に真面目に対応させました
    ・ソースコード内のボタン配置記述を将来の為に整理
    [neGcon2Switch_pico.ino]
2025-07-10 Support Controller HORI ANALOG SHINDOU PAD
    HORIアナログ振動パッドのネジコンモードに対応しました。
    頒布先のURL情報を更新しました
2025-07-11 Add I/II button swap mode and EEPROM support
    機能追加：
    ・ネジコンモードのI/IIボタン入れ替えモードを追加しました。
    ・今のネジコン設定を保存する様にしました。
    機能変更：
    ・標準コントローラのLEDの点灯パターンを変更
    ・ネジコンのI/IIボタンのMAX値対策で値を補正するようにしました(x1.1)
    バグ修正：
    ・ネジコンモード時のコントローラモードの切替出来ないバグを修正
    [neGcon2Switch_pico.ino]
2025-07-11 Update neGcon connection instructions in README
    Clarified that BOOT button toggles settings from V1.20 onwards and added a table describing LED colors for each mode. These changes improve clarity for users configuring neGcon controllers.
2025-07-13 Add max tilt setting support for neGcon/Analog Stick
    機能追加
    ・ネジコンおよびアナログスティック使用時の最大値を設定保存出来る様にしました。
2025-07-13 Update README with max angle mode and latency info
    最大角設定モードとコントローラ遅延について追記しました。
